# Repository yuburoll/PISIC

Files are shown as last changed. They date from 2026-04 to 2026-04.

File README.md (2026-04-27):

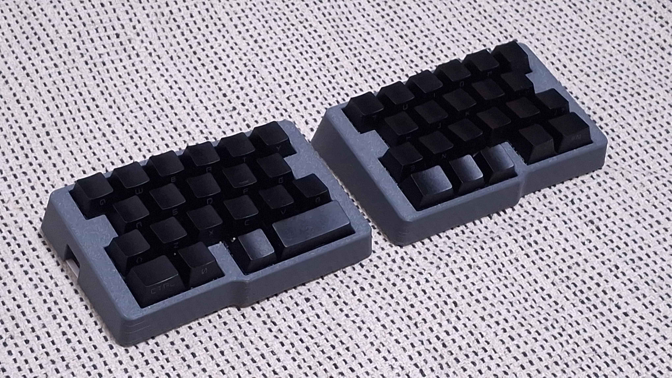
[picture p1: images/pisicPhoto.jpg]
pisicPhoto


# PISIC
42-44key row staggered split keyboard with GRIN inspired layout, under 102mm PCB

The name PISIC means grin in korean, also is korean pun of grin layout of [ansic](https://github.com/yuburoll/ANSIC).

## Preparation

- 2x pro micro form factor dev board

- 2x PISIC PCB Boards, provided from the repo

- 1x printed case sets, 2 parts total, provided from the repo

- 2x 1.5-1.6T keyboard plates, provided from the repo

- 2x 1.5-1.6T back plates, provided from the repo

- 44x diodes

- 46x Kailh hotswap sockets (or compatibles)

- 24x M2x6 screws, flathead

- 2x PJ320A 1/8(3.5mm) TRRS connector

- 2x 4x4x1.5mm surface mount tact switches (if needed)

- 8x SK6812 Mini or WS2812b Mini (3535) RGB LED (if wanted)

- 1x 1/8(3.5mm) TRRS cable

- 0-2x PCB Mounted 2u Keyboard Stabilizers, normally 1 

- 42-44x MX Keyswitches, normally 43

- 8x 10mm bumpon stickers

- A set of Keycaps

## Build Guides and Miscellaneous

[**PISIC Build Guide**](documents/buildGuide.md)

there's some notices before the build:

- **You may solder all hotswaps before soldering the dev board.**

- Assemble dev board with 2.5mm height pin headers on back side, assume that components side are faced up.

- Jump every jumpers on front side.

- Assemble Case-Plate-Switch first, not Plate-Switch-PCB.

## Default Keymap

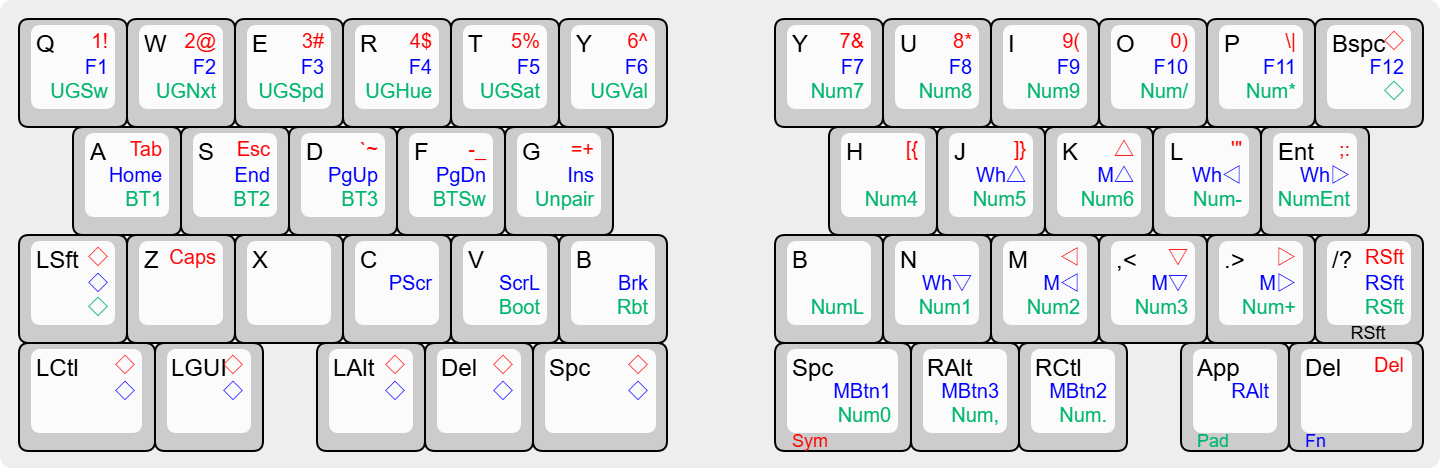
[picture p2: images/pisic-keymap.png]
pisicKeymap


There are three more layers - Sym, Fn, Pad - which can be noticed by the color legends. ◇ Means Transparent; which uses base keymap.

Holding the color legend key swaps the layer.

## Licenses

all codes follow MIT license.

all designs and the hardware board follow CC BY-SA 4.0 license.

If you want to make a commercial product, it would be appreciated if you sponsor some bucks for me.

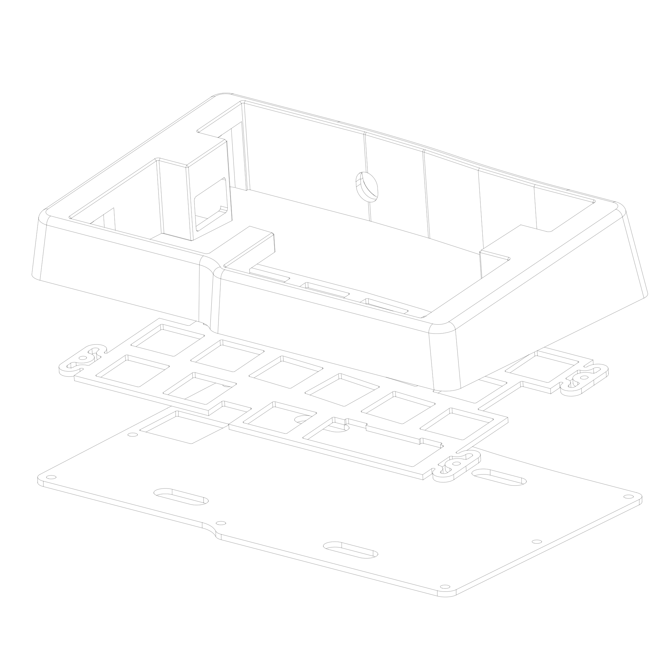
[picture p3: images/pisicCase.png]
pisicCase


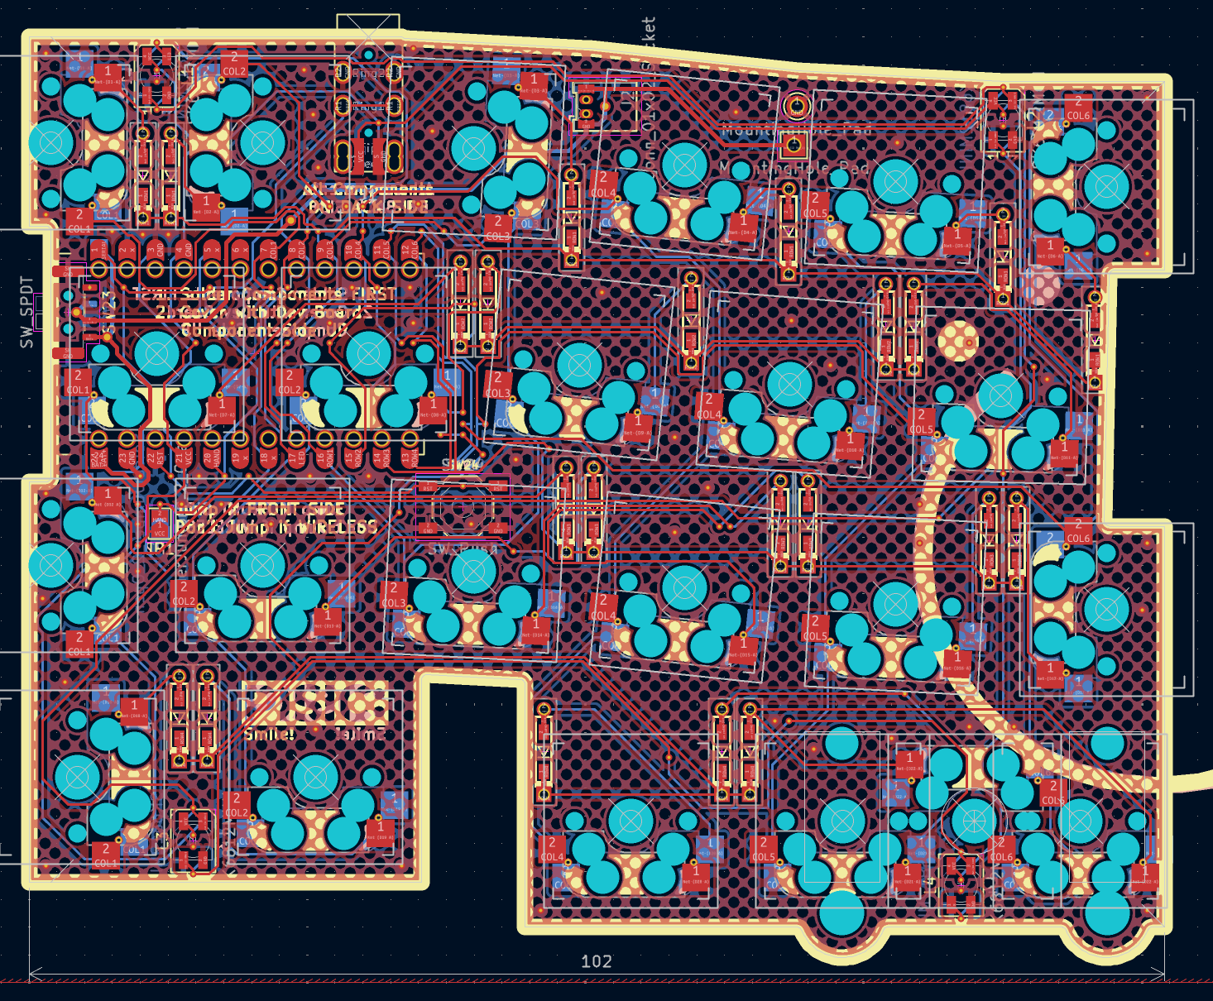
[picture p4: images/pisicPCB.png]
pisicPCB


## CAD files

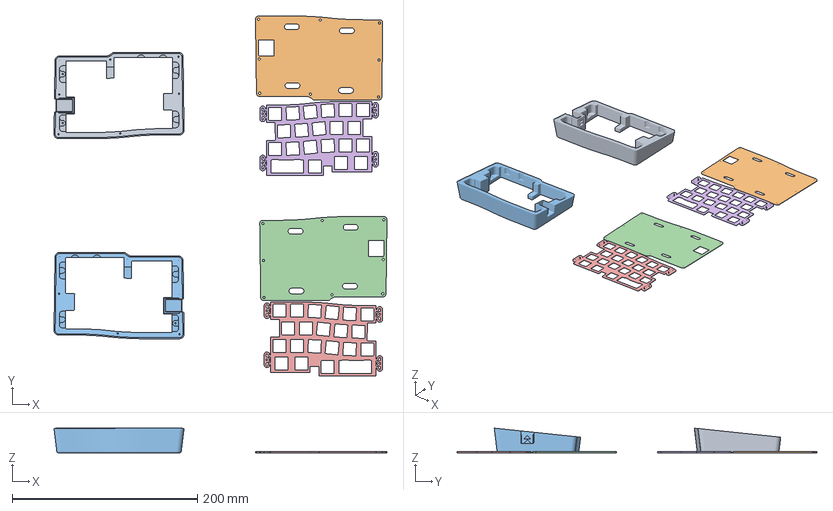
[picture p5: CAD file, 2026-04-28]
case/3mf/pisicWireless.3mf
359.5 x 388.6 x 26.7 mm
pisicCaseWirelessBridgedL.stl x 2
pisicBackplateBridgeL.stl x 2
pisicPlateL.stl x 2

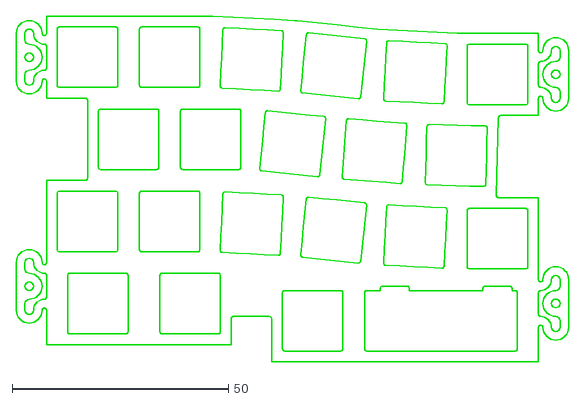
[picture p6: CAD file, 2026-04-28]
case/platesVector/pisicPlate.dxf
127.8 x 80.0

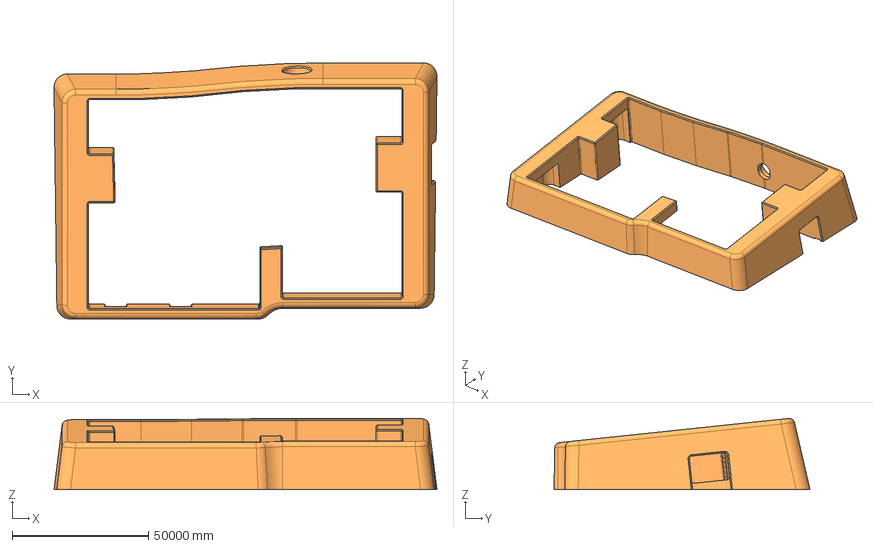
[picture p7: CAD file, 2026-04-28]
case/step/pisicCaseWiredR.stp
140382.8 x 93848.9 x 26067.8 mm

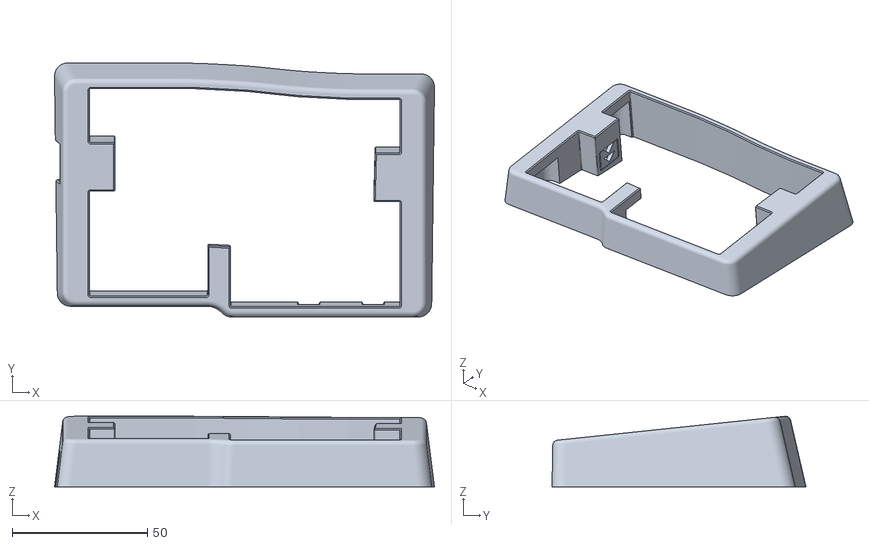
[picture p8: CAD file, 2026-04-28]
case/stl/FDMoptimized/pisicCaseWirelessBridgedL.stl
140.4 x 93.8 x 26.1

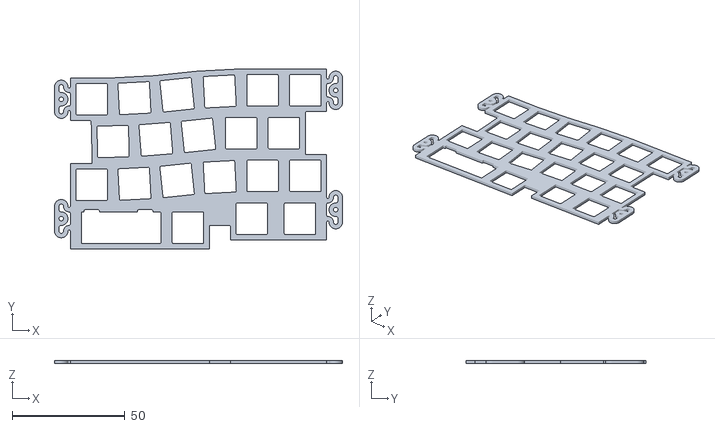
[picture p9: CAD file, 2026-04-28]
case/stl/pisicPlateR.stl
127.8 x 80.0 x 1.50

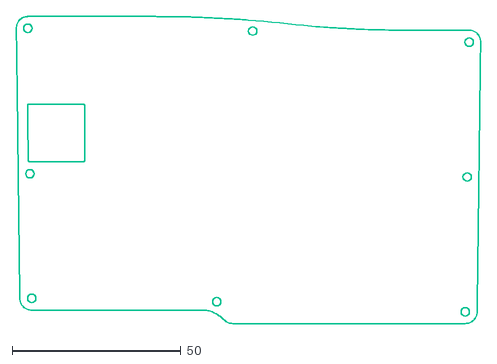
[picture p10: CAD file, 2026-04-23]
case/platesVector/pisicBackplate.dxf
137.4 x 90.9

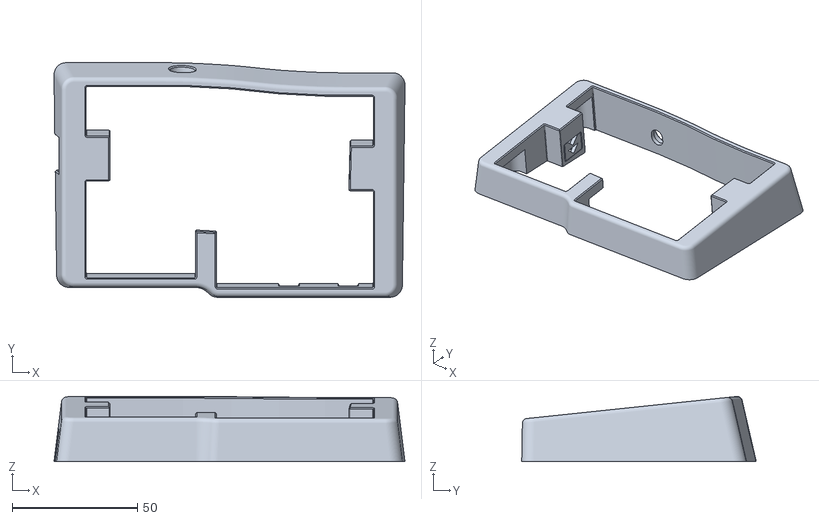
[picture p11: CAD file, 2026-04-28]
case/stl/FDMoptimized/pisicCaseWiredBridgedL.stl
140.4 x 93.8 x 26.1

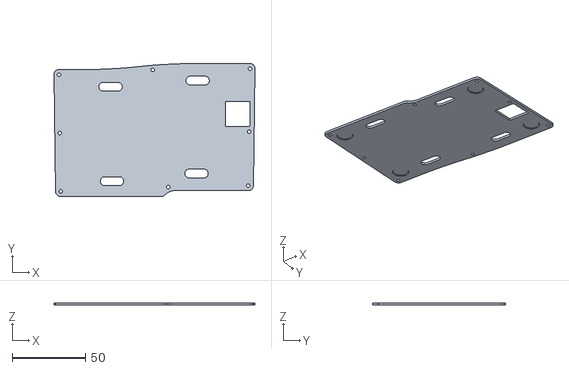
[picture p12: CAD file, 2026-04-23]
case/stl/pisicBackplateR.stl
137.4 x 90.8 x 1.50

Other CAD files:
case/3mf/pisicWired.3mf
case/step/pisicCaseWirelessR.stp
case/stl/pisicPlateL.stl
case/step/pisicCaseWirelessL.stp
case/stl/FDMoptimized/pisicCaseWiredBridgedR.stl
case/step/pisicCaseWiredL.stp
case/stl/FDMoptimized/pisicCaseWirelessBridgedR.stl
case/stl/pisicBackplateL.stl
case/stl/FDMoptimized/pisicBackplateBridgeL.stl
case/stl/FDMoptimized/pisicBackplateBridgeR.stl
case/raw/pisic.3dm
case/stl/pisicCaseWiredL.stl
case/stl/pisicCaseWiredR.stl
case/stl/pisicCaseWirelessL.stl
case/stl/pisicCaseWirelessR.stl

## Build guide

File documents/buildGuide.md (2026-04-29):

# Build Guide
this is build guide for PISIC.

the build guide contains photo of prototype version. newest version have following differences:

- the rims between first row and third row are 4mm wider, for easier assembly. these PCB have outline silkscreen.

- the corner screws of case aside fourth row are enforced, so they also have different plate design.

This documents are translated by generative AI, so there can be some misleading texts.

### Additional Resources
[**Soldering Tips**](solderingTip.md)

# PCB Preparation
Prepare two PCBs for the PISIC. Since these are reversible PCBs, be careful to place components on different sides for each board.

The side where components will be placed is treated as the back, and the side without components is treated as the front. **All components go on back side only, so please be careful when soldering.**

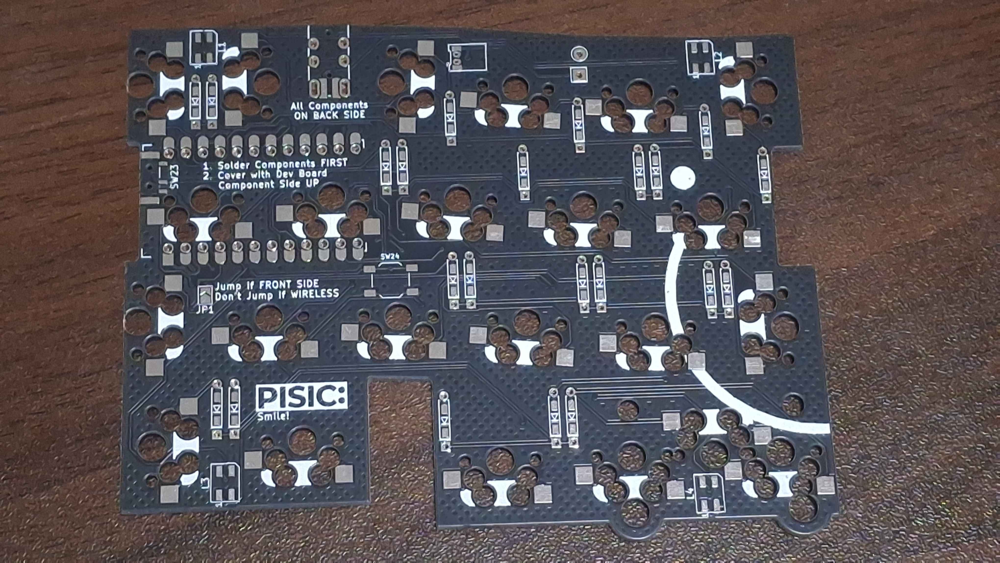
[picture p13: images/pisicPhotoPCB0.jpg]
pisicPhotoPCB0

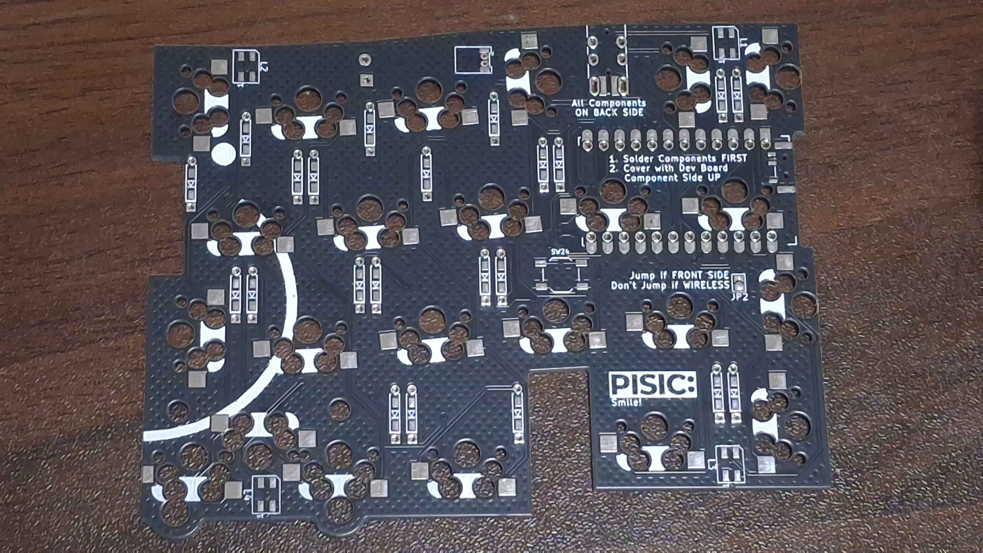
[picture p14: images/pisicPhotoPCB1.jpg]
pisicPhotoPCB1


# Soldering the Diodes
Solder the diodes. The photos show SMD diodes being used, but THT diodes can also be used.

When using SMD diodes, first apply a solder blob to one side of the pad with a soldering iron, as shown in the following photo.

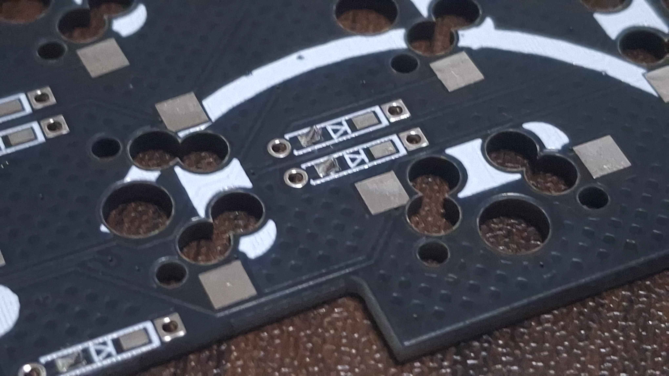
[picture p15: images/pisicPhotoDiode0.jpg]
pisicPhotoDiode0


Reheat the solder blob with the iron to melt it, align the diode in the correct orientation and place it in position, then remove the iron.

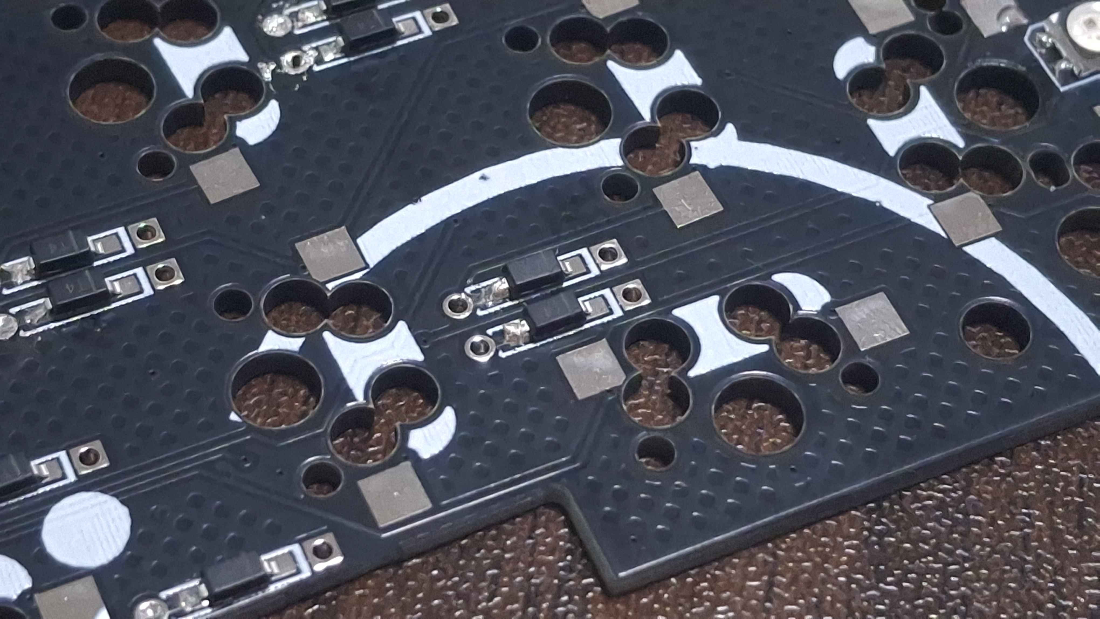
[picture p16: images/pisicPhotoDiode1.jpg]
pisicPhotoDiode1


Once it is seated properly, solder the opposite leg.

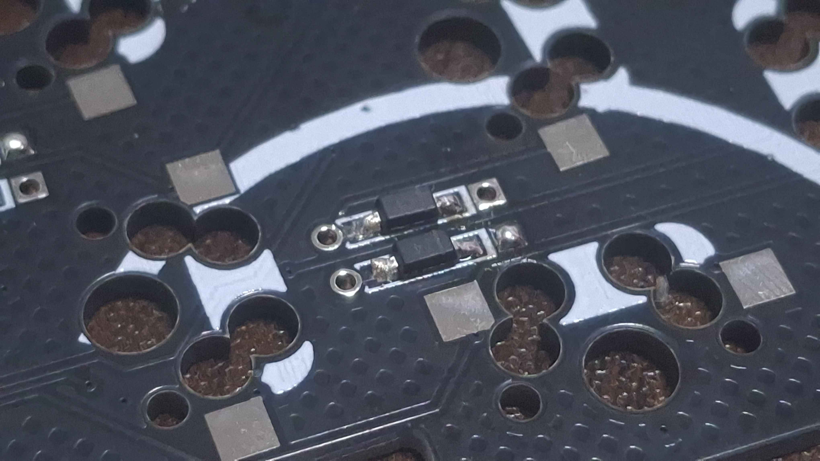
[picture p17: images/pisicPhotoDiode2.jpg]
pisicPhotoDiode2


# (Optional) Soldering the LEDs
Solder the underglow LEDs. The process is largely the same as soldering SMD diodes, but extra care is needed when applying heat.

First, apply a solder blob to one side of the pad with a soldering iron, as shown in the following photo.

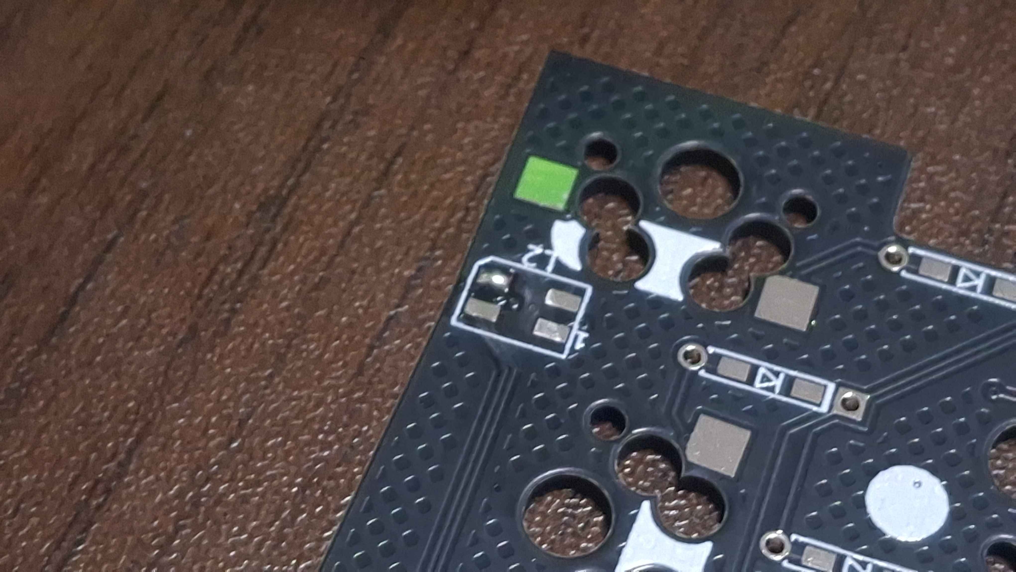
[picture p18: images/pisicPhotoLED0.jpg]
pisicPhotoLED0


Reheat the solder blob with the iron to melt it, align the LED in the correct orientation and place it in position, then remove the iron.

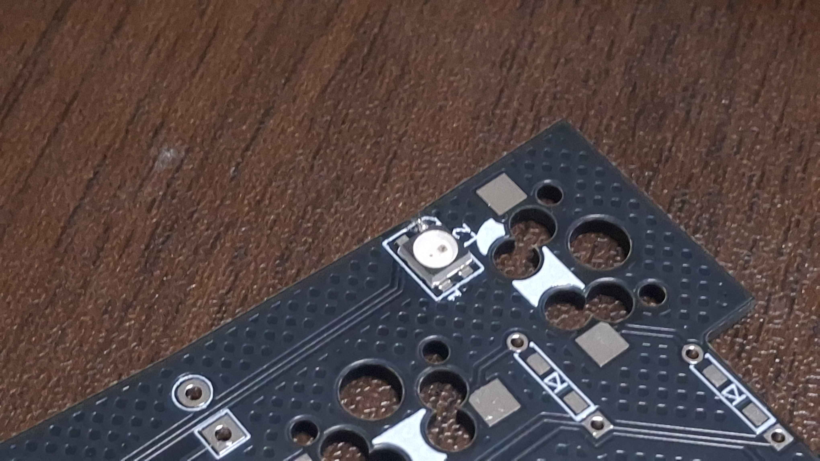
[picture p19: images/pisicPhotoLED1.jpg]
pisicPhotoLED1


Once it is seated properly, carefully solder the remaining three pads. Note that solder may not flow into them easily, so take care.

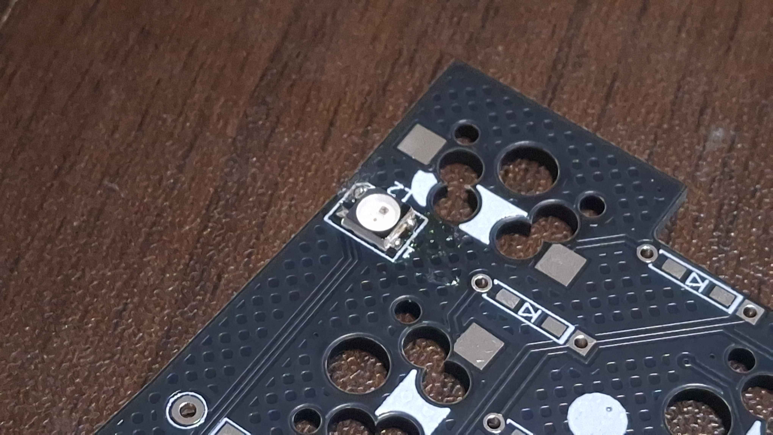
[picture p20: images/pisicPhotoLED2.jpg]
pisicPhotoLED2


# Soldering the Hot-swap Sockets
Solder the hot-swap sockets. The process is largely the same as soldering the diodes and LEDs.

As before, apply a solder blob to one side of the pad, reheat the blob to melt it, place the component and hold it in position, remove the iron, then solder the opposite leg.

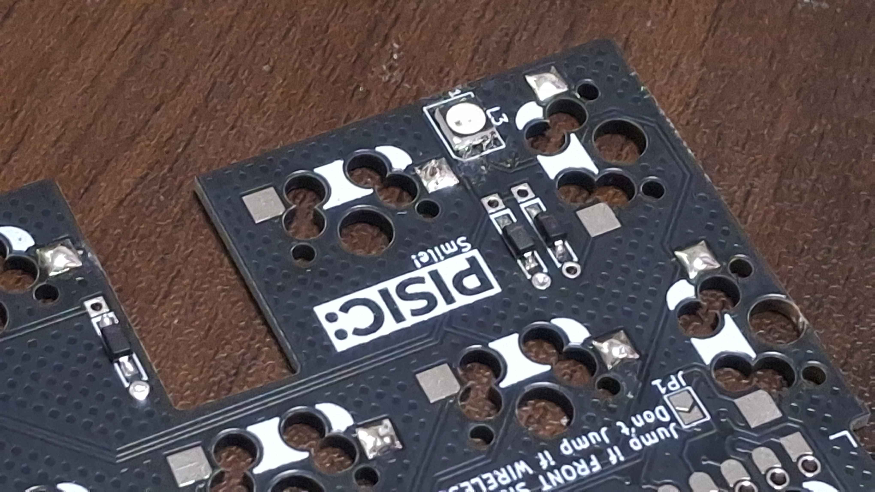
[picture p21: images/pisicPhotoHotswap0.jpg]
pisicPhotoHotswap0

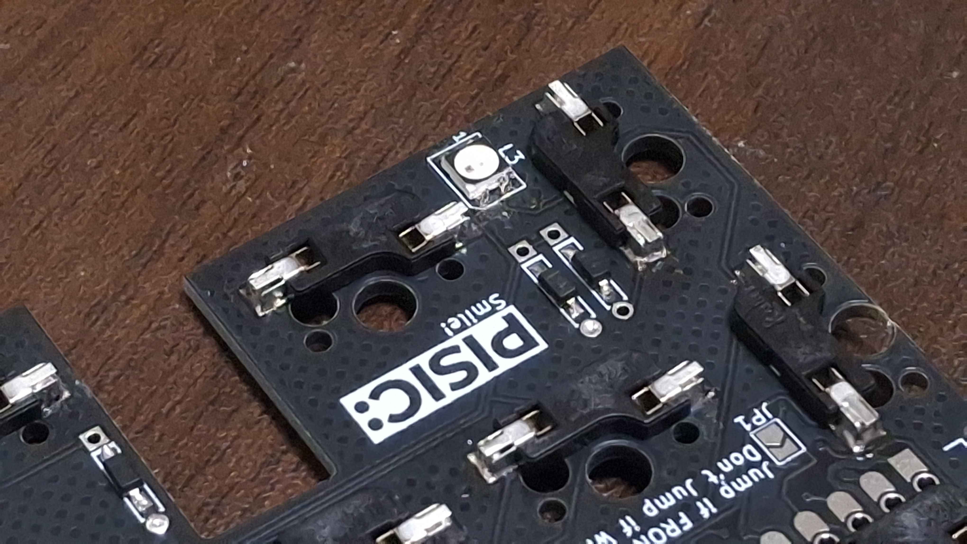
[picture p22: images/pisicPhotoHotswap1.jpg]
pisicPhotoHotswap1


# Soldering the TRRS Jack
Refer to the following photos to identify where the TRRS jack will be placed.

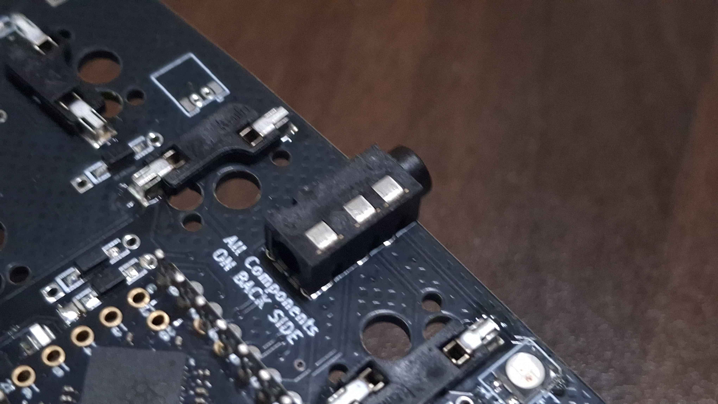
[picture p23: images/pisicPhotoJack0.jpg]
pisicPhotoJack0

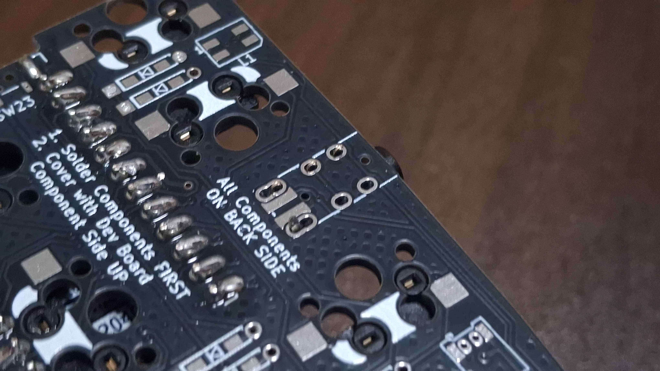
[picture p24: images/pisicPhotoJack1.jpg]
pisicPhotoJack1


Solder the TRRS jack. When soldering the Tip and Sleeve pins, also bridge them to the adjacent pads as shown in the photo.

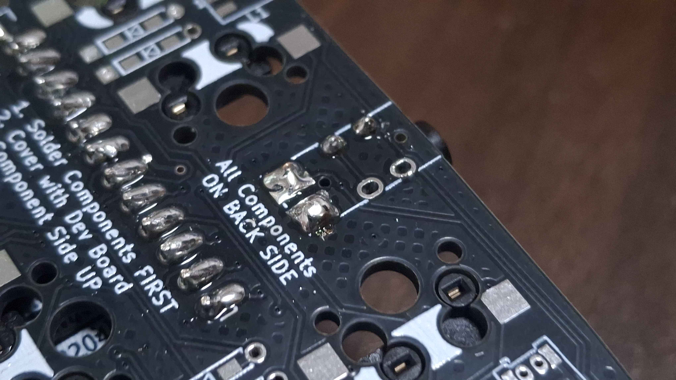
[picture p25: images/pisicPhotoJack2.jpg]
pisicPhotoJack2


# Soldering the Dev Board
First, check the header pins on the provided Pro Micro dev board. The outermost row of header pins past 5V is not needed, so trim them off.

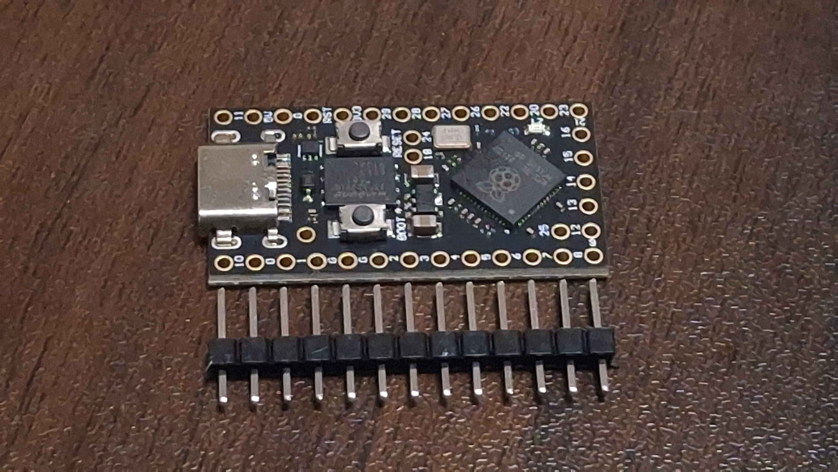
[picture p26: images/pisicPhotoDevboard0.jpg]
pisicPhotoDevboard0

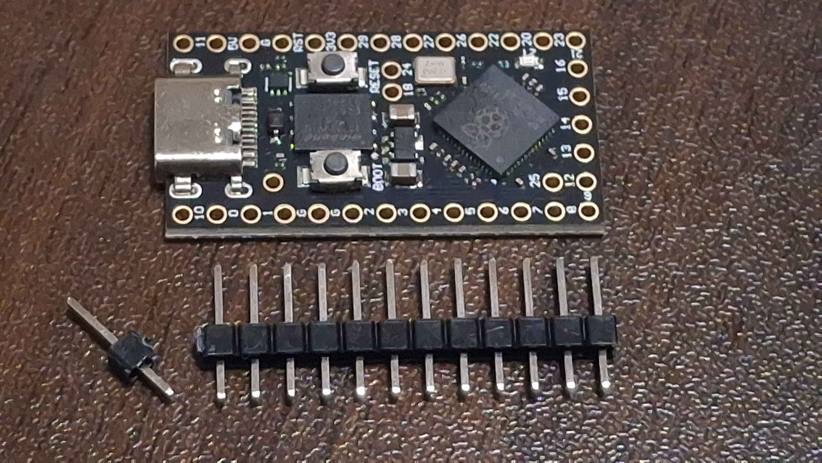
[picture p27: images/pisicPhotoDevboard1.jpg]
pisicPhotoDevboard1


Insert the header pins starting from 5V, align them, and solder the dev board. When soldering, make sure the components face upward as shown in the photo.

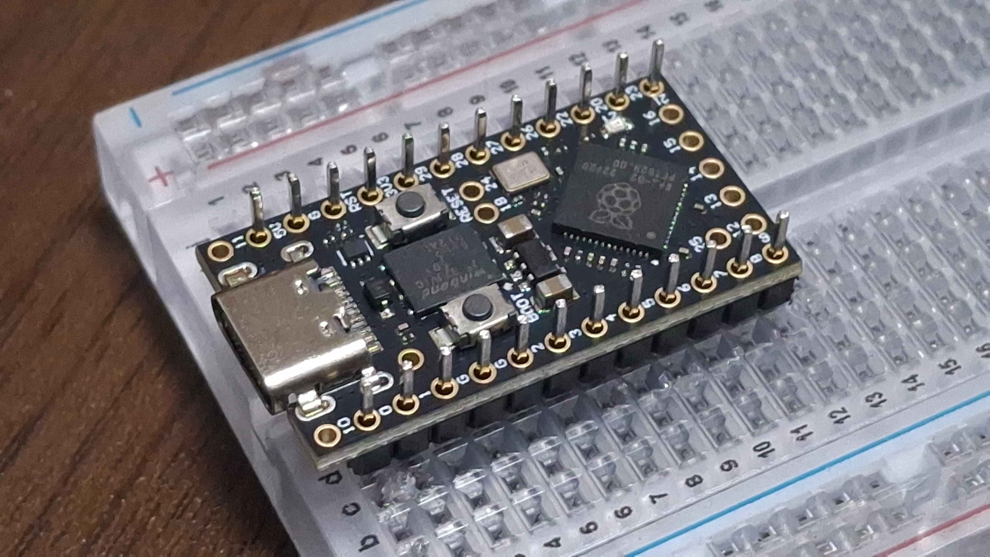
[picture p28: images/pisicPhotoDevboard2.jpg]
pisicPhotoDevboard2

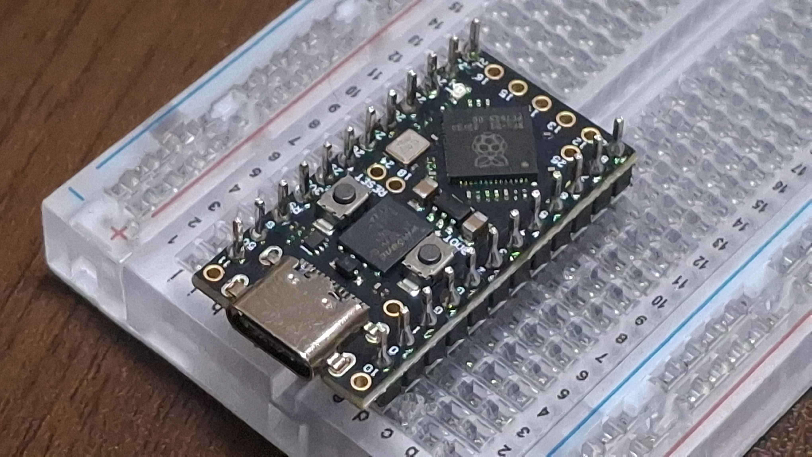
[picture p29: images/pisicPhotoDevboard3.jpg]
pisicPhotoDevboard3


Place the dev board with the soldered header pins on top of the already-soldered hot-swap sockets. Press down firmly to ensure a tight fit.

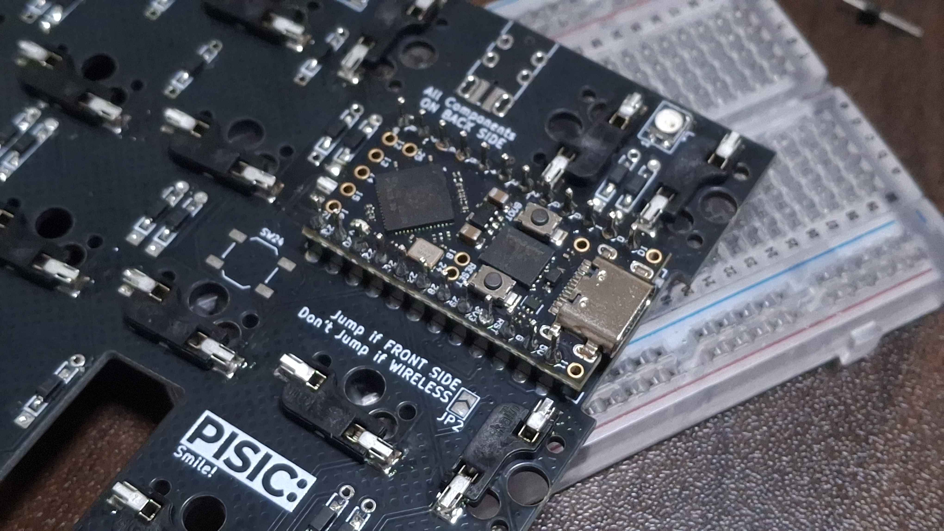
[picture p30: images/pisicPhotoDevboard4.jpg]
pisicPhotoDevboard4

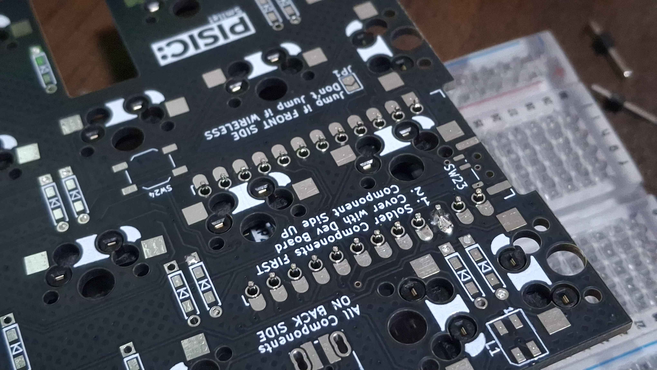
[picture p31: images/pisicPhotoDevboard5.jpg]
pisicPhotoDevboard5


Just like when soldering the TRRS jack pins, bridge the header pins to the adjacent pads as if soldering jumpers. Since a large amount of solder is used, there is a risk of bridging with flux, so be sure to clean the area with alcohol after soldering.

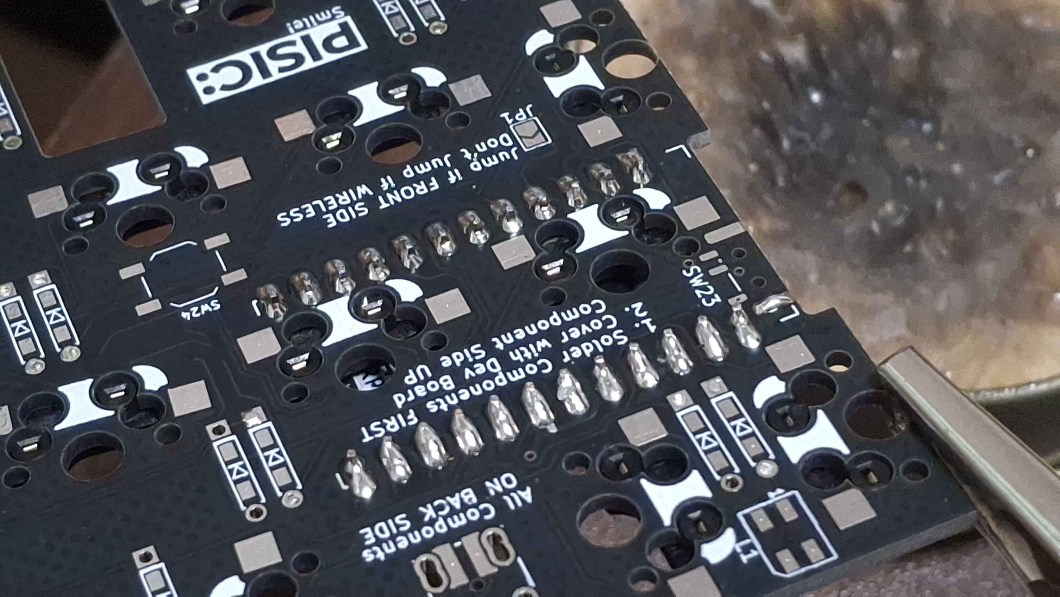
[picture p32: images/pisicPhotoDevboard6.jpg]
pisicPhotoDevboard6


# Soldering the Jumpers
On the front side seen when soldering the dev board, bridge the jumpers located just below. Apply enough solder so that a blob forms on top.

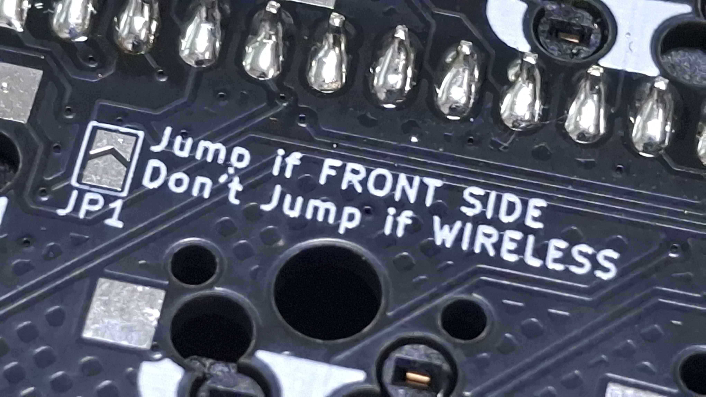
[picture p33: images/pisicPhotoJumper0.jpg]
pisicPhotoJumper0

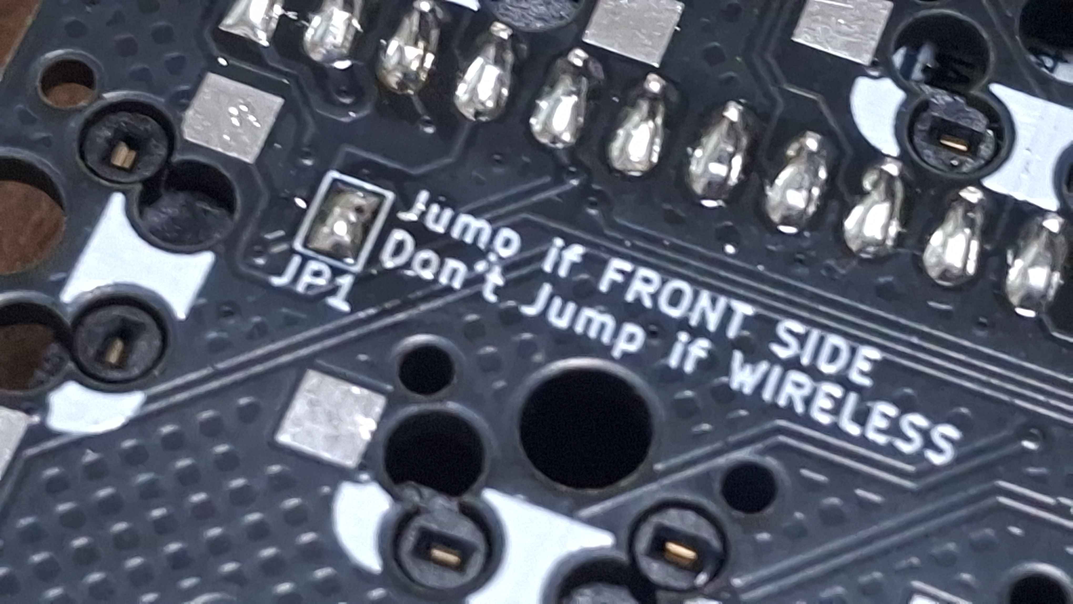
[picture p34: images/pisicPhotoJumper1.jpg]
pisicPhotoJumper1


# Check before Assembly
a finished right side of PCB looks like following images. mirror it on the left side.

the photo didn't jumped the front jumper, but you may jump there if you building wired version.

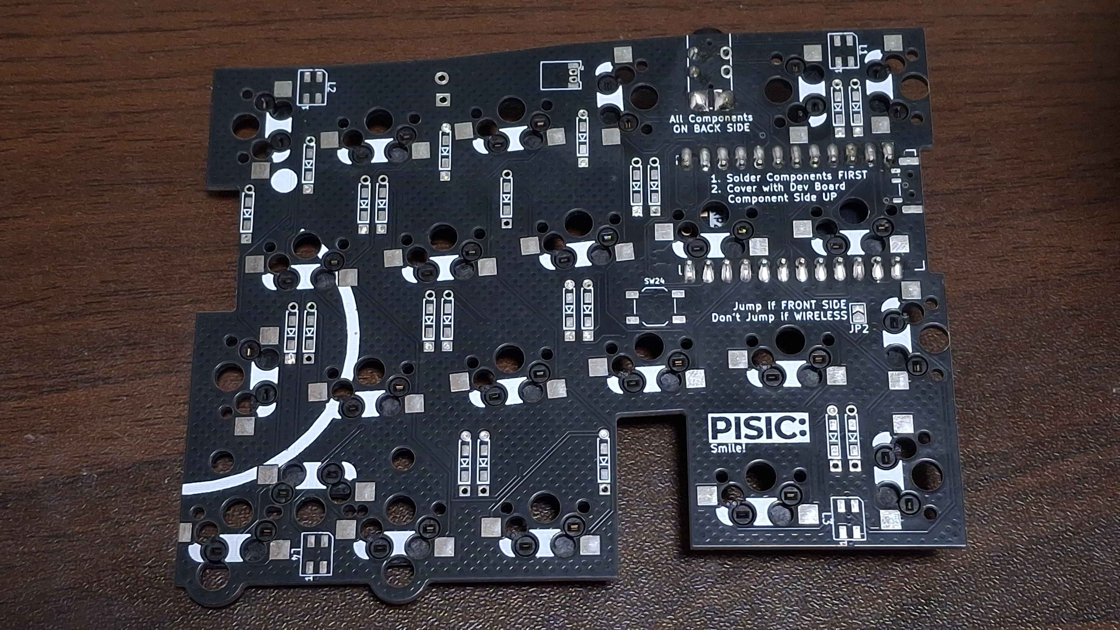
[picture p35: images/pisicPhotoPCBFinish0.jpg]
pisicPhotoPCBFinish0

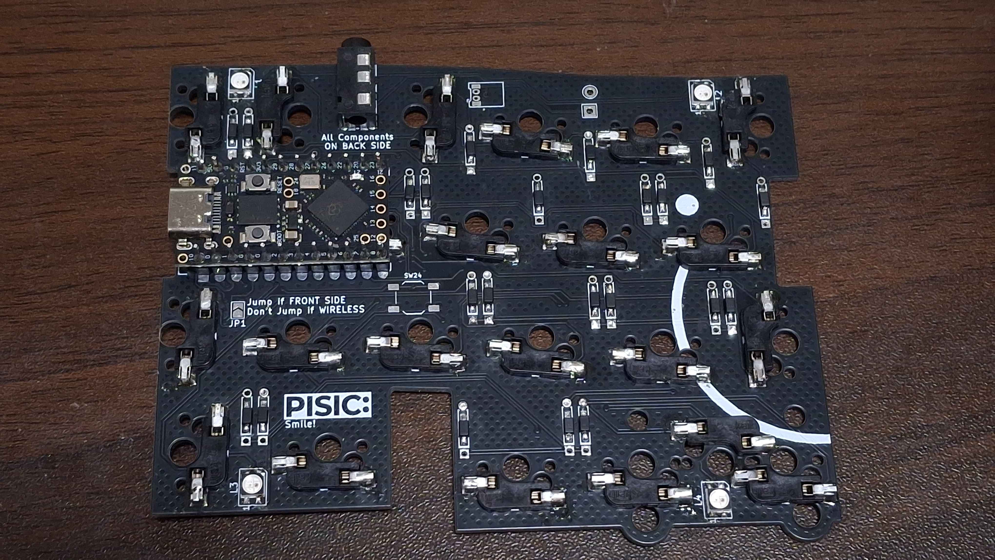
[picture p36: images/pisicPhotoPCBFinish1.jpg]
pisicPhotoPCBFinish1


# Assembly
First, assemble the case, plate, and switches together. (Note: If you assemble the plate, switches, and PCB first, the assembly will not fit into the case.)
The plate and case are fastened together with screws at four points.

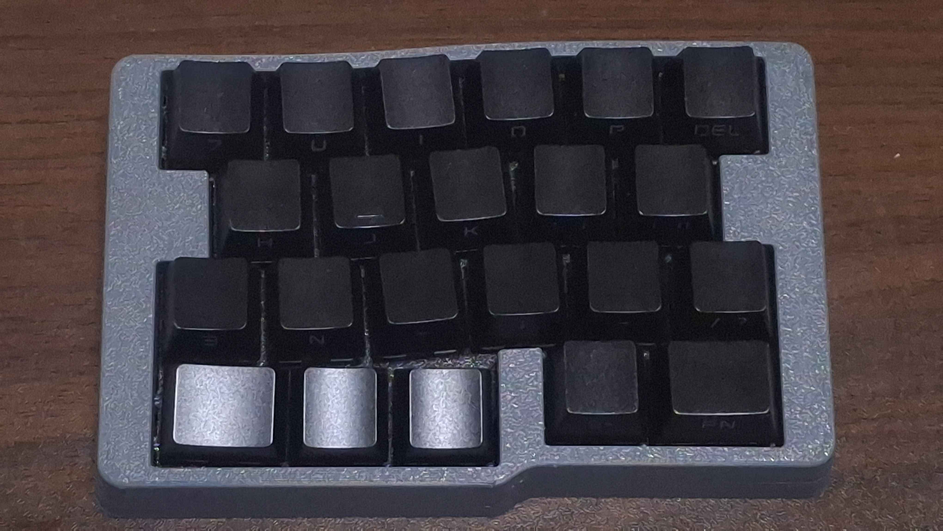
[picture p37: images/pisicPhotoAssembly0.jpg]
pisicPhotoAssembly0

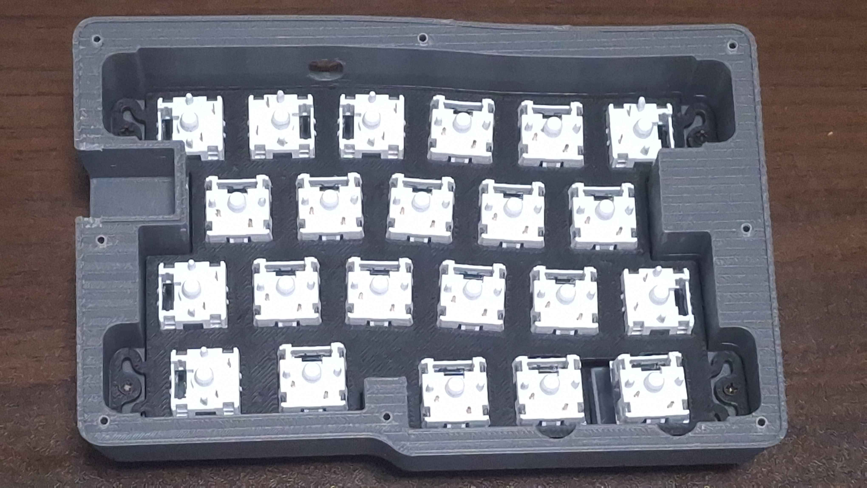
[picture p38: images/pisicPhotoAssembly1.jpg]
pisicPhotoAssembly1


Insert the protruding part of the TRRS jack into the hole in the case, then lower the PCB onto the switches to mate them together.

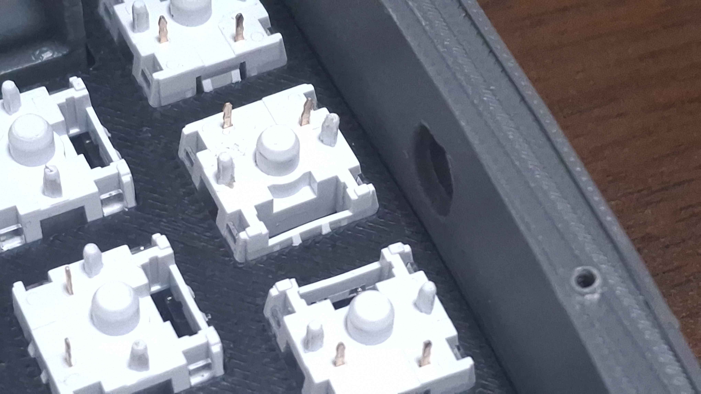
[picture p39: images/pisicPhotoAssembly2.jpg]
pisicPhotoAssembly2

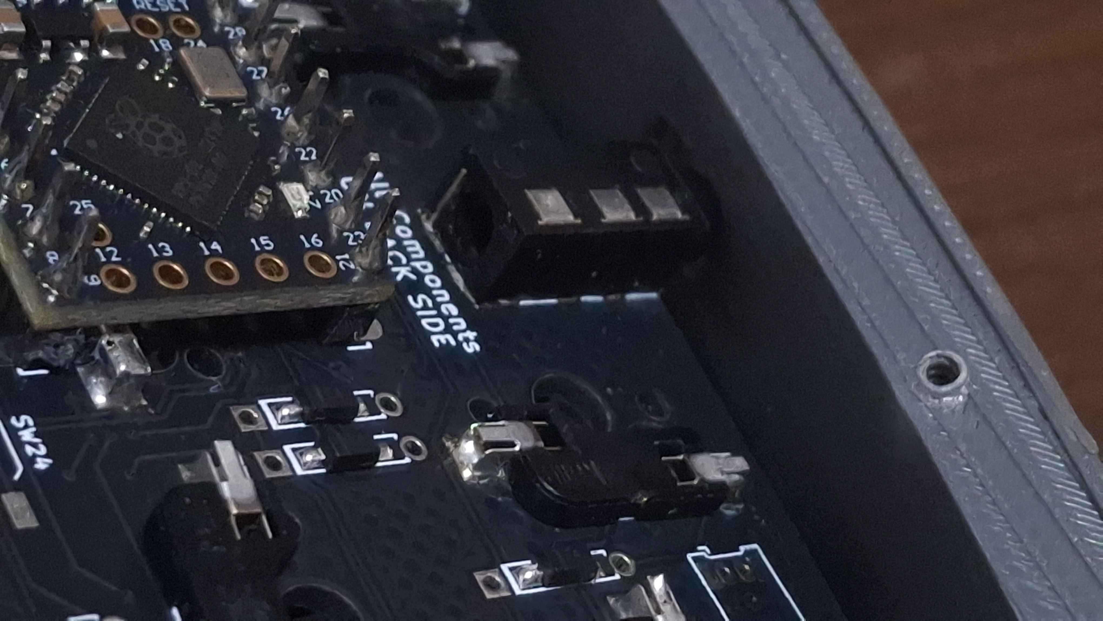
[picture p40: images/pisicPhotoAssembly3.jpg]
pisicPhotoAssembly3


Place the backplate over the case and fasten it with screws at eight points per side to complete the build.

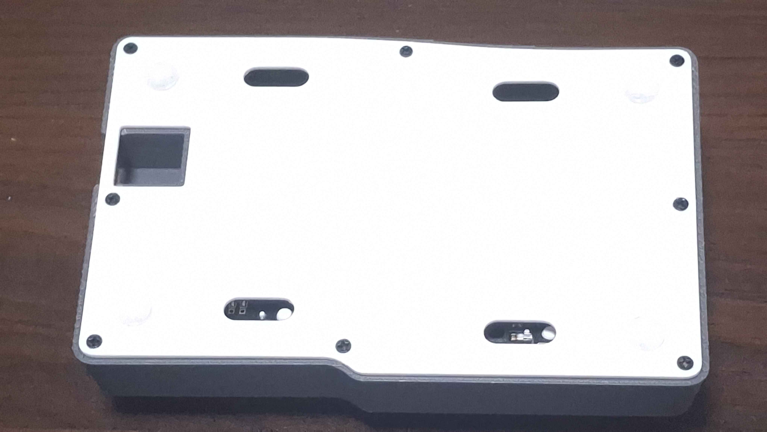
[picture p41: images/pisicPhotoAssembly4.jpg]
pisicPhotoAssembly4


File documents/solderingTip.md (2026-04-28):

# Soldering Tips

A collection of soldering advice and tips.

This documents are translated by generative AI, so there can be some misleading texts.

## Supplies

- Soldering iron & stand: A chisel tip is the most convenient to work with. I recommend getting one that can maintain a temperature of at least 400–500°C.

- Solder: Choose between leaded and lead-free solder. Leaded solder is less stressful to work with, but it is not good for your health.

- Solder paste (flux): **The god of soldering.** If your solder joints are not turning out well, frequently wipe and coat the iron tip with paste flux.

- Damp sponge/paper towel, or a tip cleaner (brass wool): Used to wipe residual solder off the iron tip.

- Solder wick or solder sucker: Used to fix bad solder joints. For beginners, solder wick is recommended.

- Flush cutters: Used to clip the legs of THT diodes after soldering.

## Ventilate Your Workspace

The metal fumes from melting solder are a concern, but they are actually quite minimal. The bigger issue is the smoke from the rosin flux inside the solder burning and melting — it is quite harmful and produces a lot of smoke. It is very bad for your health, so ventilate the area, or if ventilation is not possible, make sure to use an air purifier. Always wear a mask.

## Double-Check Before Soldering Components

It is easier to prevent a bad solder joint than to fix one. To correct a solder joint, apply flux to solder wick and press it against the joint with the iron, or apply a small amount of flux to the iron tip, melt the solder, and simultaneously press a solder sucker against it to absorb the solder.

## Apply Flux If Solder Is Not Sticking

Melt flux onto the iron tip to coat it, or use a flux pen to apply it directly to the PCB pads.

## Touch the Iron First When Starting, Remove It Last When Finishing

Place the iron on the pad first to preheat the PCB and component, then melt the solder onto the joint. When finishing, remove the solder first, then remove the iron last.

## Use Masking Tape to Temporarily Hold Components

For components like sockets, securing them with masking tape before soldering is helpful. This is especially important when you need to flip the board over, as components can be difficult to hold in place.

## Clean the Flux After Soldering

Scrub the remaining flux and any areas prone to short circuits thoroughly using a toothbrush dipped in isopropyl alcohol. You can also spray alcohol on the board, scrub with a toothbrush, and let it dry. Keyboard key inputs may work fine with residual flux, but encoders and analog inputs are more susceptible to issues caused by flux bridging.

## If Something Goes Wrong, Reflow and Clean

Problems can arise from cold joints, insufficient solder, excess solder bridging neighboring pads, or electrical interference from flux residue. In most cases, reflowing the solder joint and cleaning the flux will resolve the issue.

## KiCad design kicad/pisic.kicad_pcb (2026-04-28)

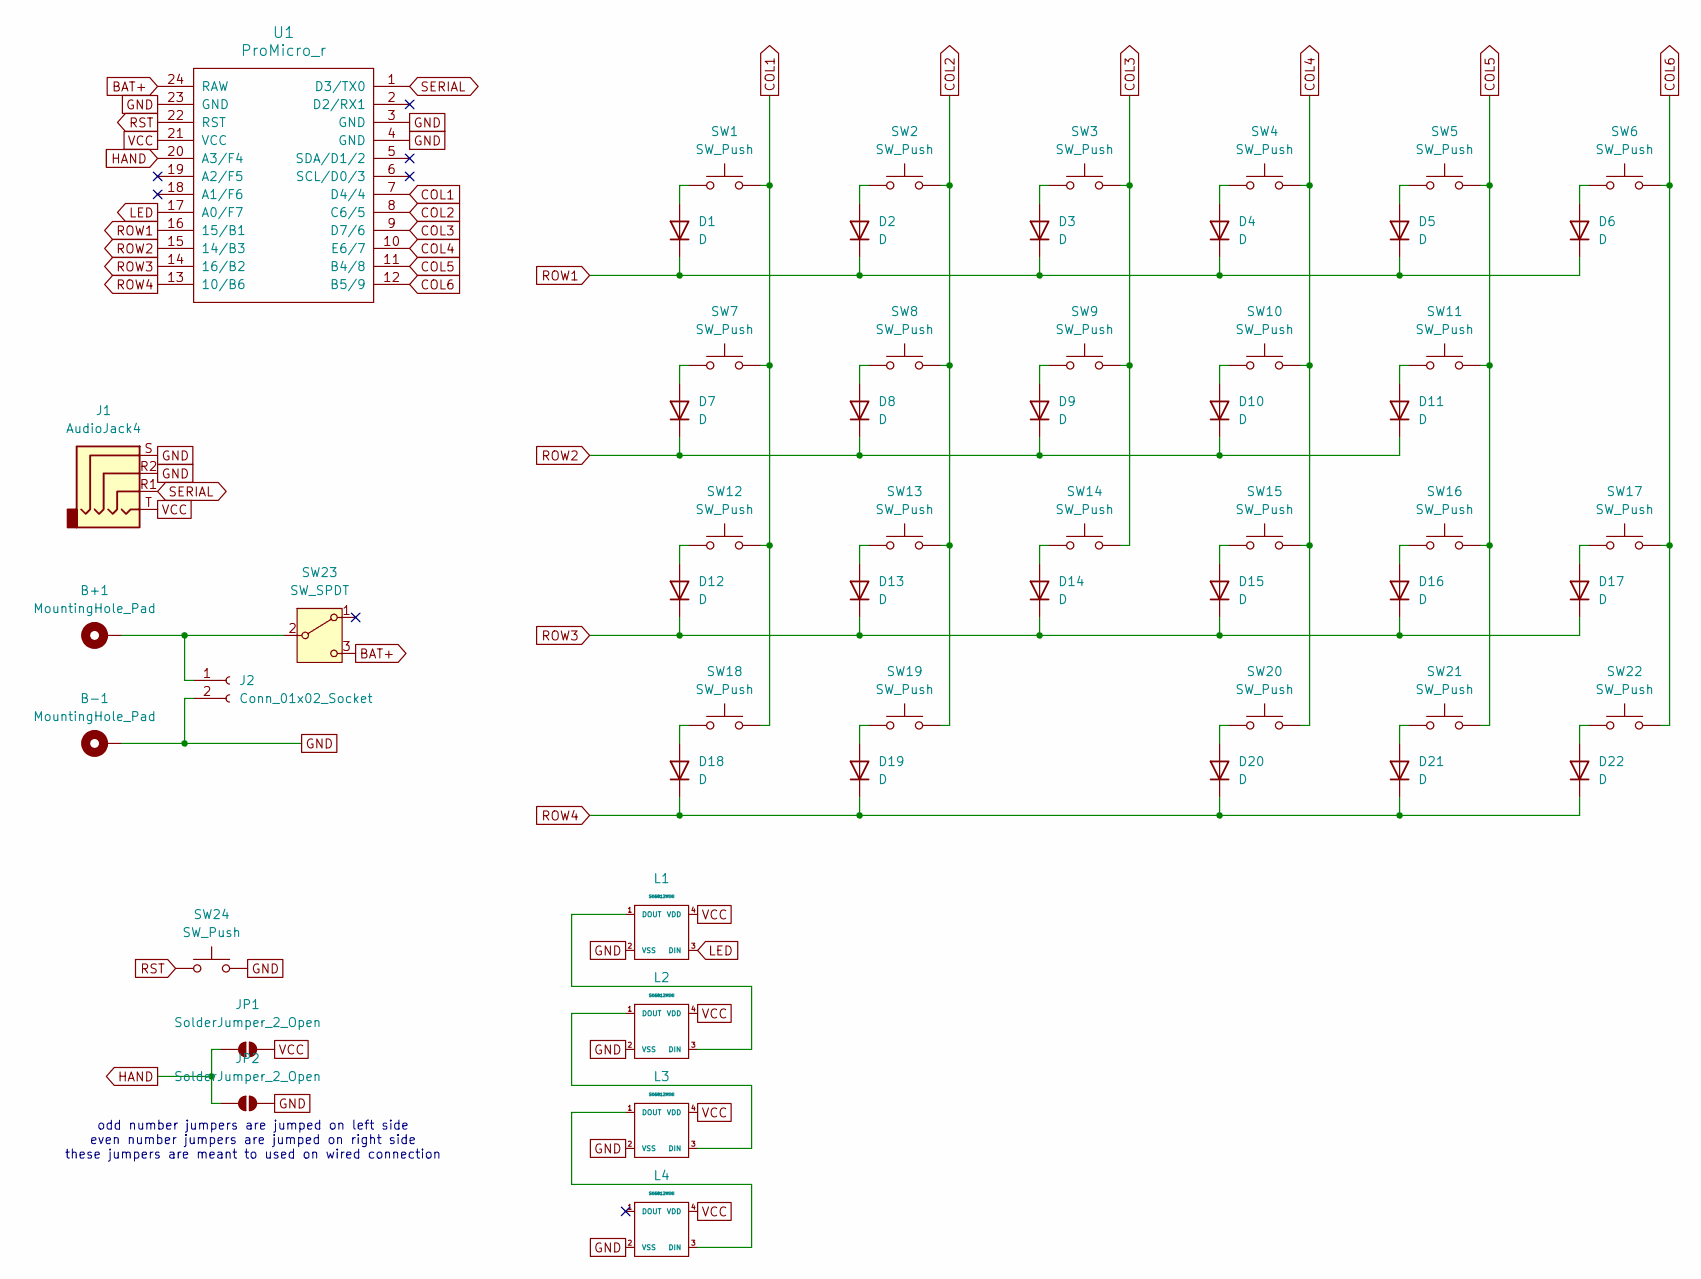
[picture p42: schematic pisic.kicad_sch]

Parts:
B+1: MountingHole_Pad
B-1: MountingHole_Pad
D1, D2, D3, D4, D5, D6, D7, D8, D9, D10, D11, D12, D13, D14, D15, D16, D17, D18, D19, D20, D21, D22: D
J1: AudioJack4
J2: Conn_01x02_Socket
JP1, JP2: SolderJumper_2_Open
L1, L2, L3, L4: SK6812MINI
SW1, SW2, SW3, SW4, SW5, SW6, SW7, SW8, SW9, SW10, SW11, SW12, SW13, SW14, SW15, SW16, SW17, SW18, SW19, SW20, SW21, SW22, SW24: SW_Push
SW23: SW_SPDT
U1: ProMicro_r

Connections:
BAT+: SW23.3 (C), U1.24 (RAW)
COL1: SW1.2, SW7.2, SW12.2, SW18.2, U1.7 (D4/4)
COL2: SW2.2, SW8.2, SW13.2, SW19.2, U1.8 (C6/5)
COL3: SW3.2, SW9.2, SW14.2, U1.9 (D7/6)
COL4: SW4.2, SW10.2, SW15.2, SW20.2, U1.10 (E6/7)
COL5: SW5.2, SW11.2, SW16.2, SW21.2, U1.11 (B4/8)
COL6: SW6.2, SW17.2, SW22.2, U1.12 (B5/9); also elsewhere on the board
GND: B-1.1, J1.R2, J1.S, J2.2, JP2.1 (A), L1.2 (VSS), L2.2 (VSS), L3.2 (VSS), L4.2 (VSS), SW23.SH, SW24.2, U1.3 (GND), U1.4 (GND), U1.23 (GND); also elsewhere on the board
HAND: JP1.2 (B), JP2.2 (B), U1.20 (A3/F4)
LED: L1.3 (DIN), U1.17 (A0/F7); also elsewhere on the board
unnamed: D1.2 (A), SW1.1
unnamed: D2.2 (A), SW2.1
unnamed: D3.2 (A), SW3.1
unnamed: D4.2 (A), SW4.1
unnamed: D5.2 (A), SW5.1
unnamed: D6.2 (A), SW6.1
unnamed: D7.2 (A), SW7.1
unnamed: D8.2 (A), SW8.1
unnamed: D9.2 (A), SW9.1
unnamed: D10.2 (A), SW10.1
unnamed: D11.2 (A), SW11.1
unnamed: D12.2 (A), SW12.1
unnamed: D13.2 (A), SW13.1
unnamed: D14.2 (A), SW14.1
unnamed: D15.2 (A), SW15.1
unnamed: D16.2 (A), SW16.1
unnamed: D17.2 (A), SW17.1
unnamed: D18.2 (A), SW18.1
unnamed: D19.2 (A), SW19.1
unnamed: D20.2 (A), SW20.1
unnamed: D21.2 (A), SW21.1
unnamed 31: D22.2 (A), SW22.1; also elsewhere on the board
unnamed: B+1.1, J2.1, SW23.2 (B)
unnamed 33: L1.1 (DOUT), L2.3 (DIN); also elsewhere on the board
unnamed 34: L2.1 (DOUT), L3.3 (DIN); also elsewhere on the board
unnamed 35: L3.1 (DOUT), L4.3 (DIN); also elsewhere on the board
ROW1: D1.1 (K), D2.1 (K), D3.1 (K), D4.1 (K), D5.1 (K), D6.1 (K), U1.16 (15/B1)
ROW2: D7.1 (K), D8.1 (K), D9.1 (K), D10.1 (K), D11.1 (K), U1.15 (14/B3)
ROW3: D12.1 (K), D13.1 (K), D14.1 (K), D15.1 (K), D16.1 (K), D17.1 (K), U1.14 (16/B2)
ROW4: D18.1 (K), D19.1 (K), D20.1 (K), D21.1 (K), D22.1 (K), U1.13 (10/B6)
RST: SW24.1, U1.22 (RST); also elsewhere on the board
SERIAL: J1.R1, U1.1 (D3/TX0)
VCC: J1.T, JP1.1 (A), L1.4 (VDD), L2.4 (VDD), L3.4 (VDD), L4.4 (VDD), U1.21 (VCC); also elsewhere on the board

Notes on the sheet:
odd number jumpers are jumped on left side even number jumpers are jumped on right side these jumpers are meant to used on wired connection

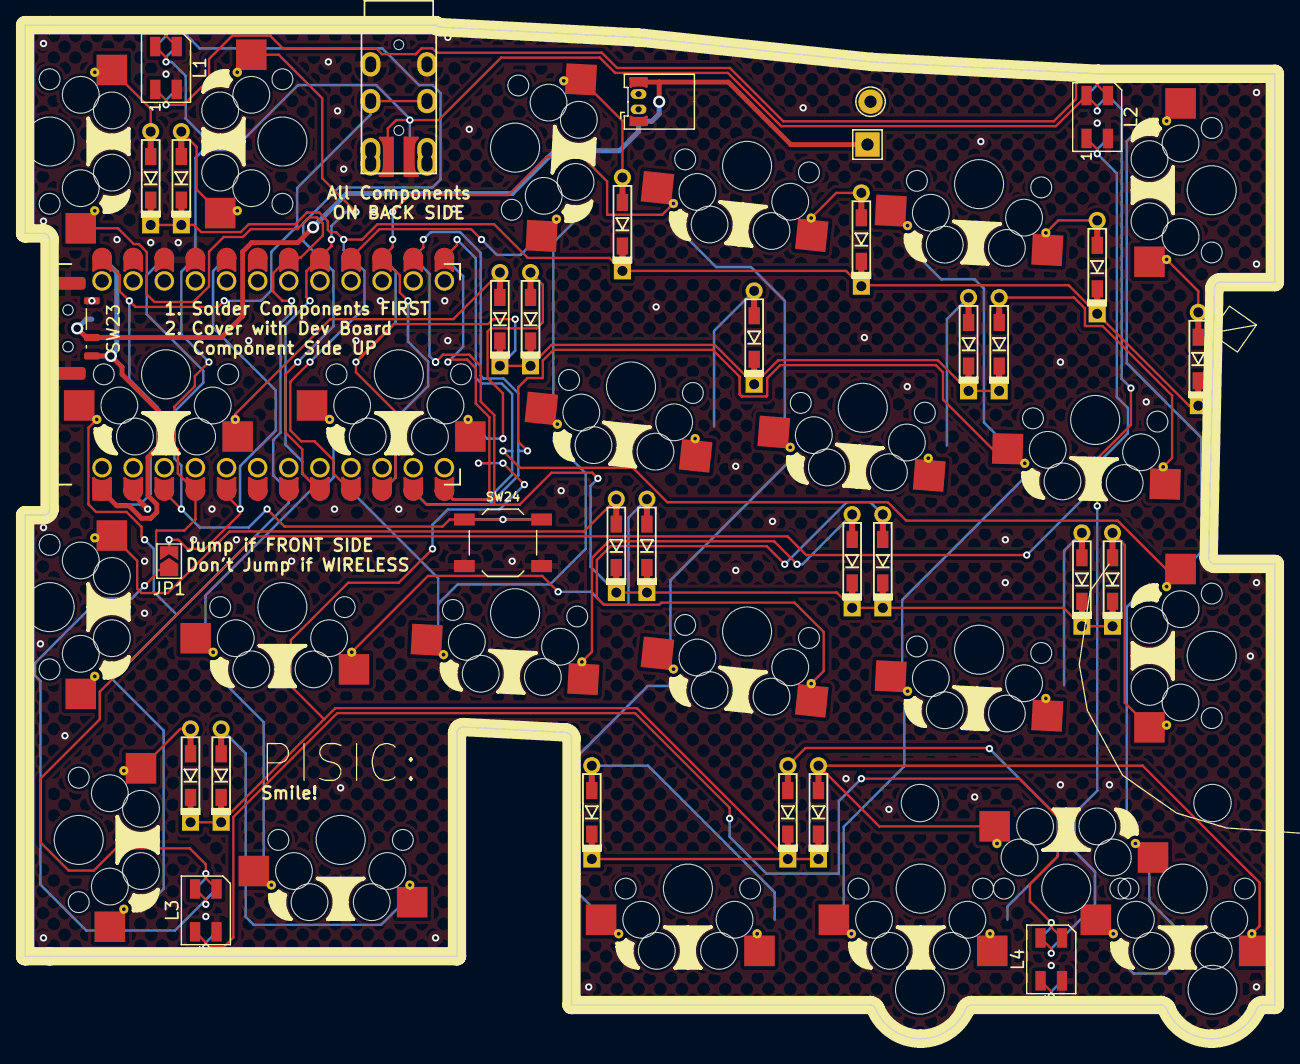
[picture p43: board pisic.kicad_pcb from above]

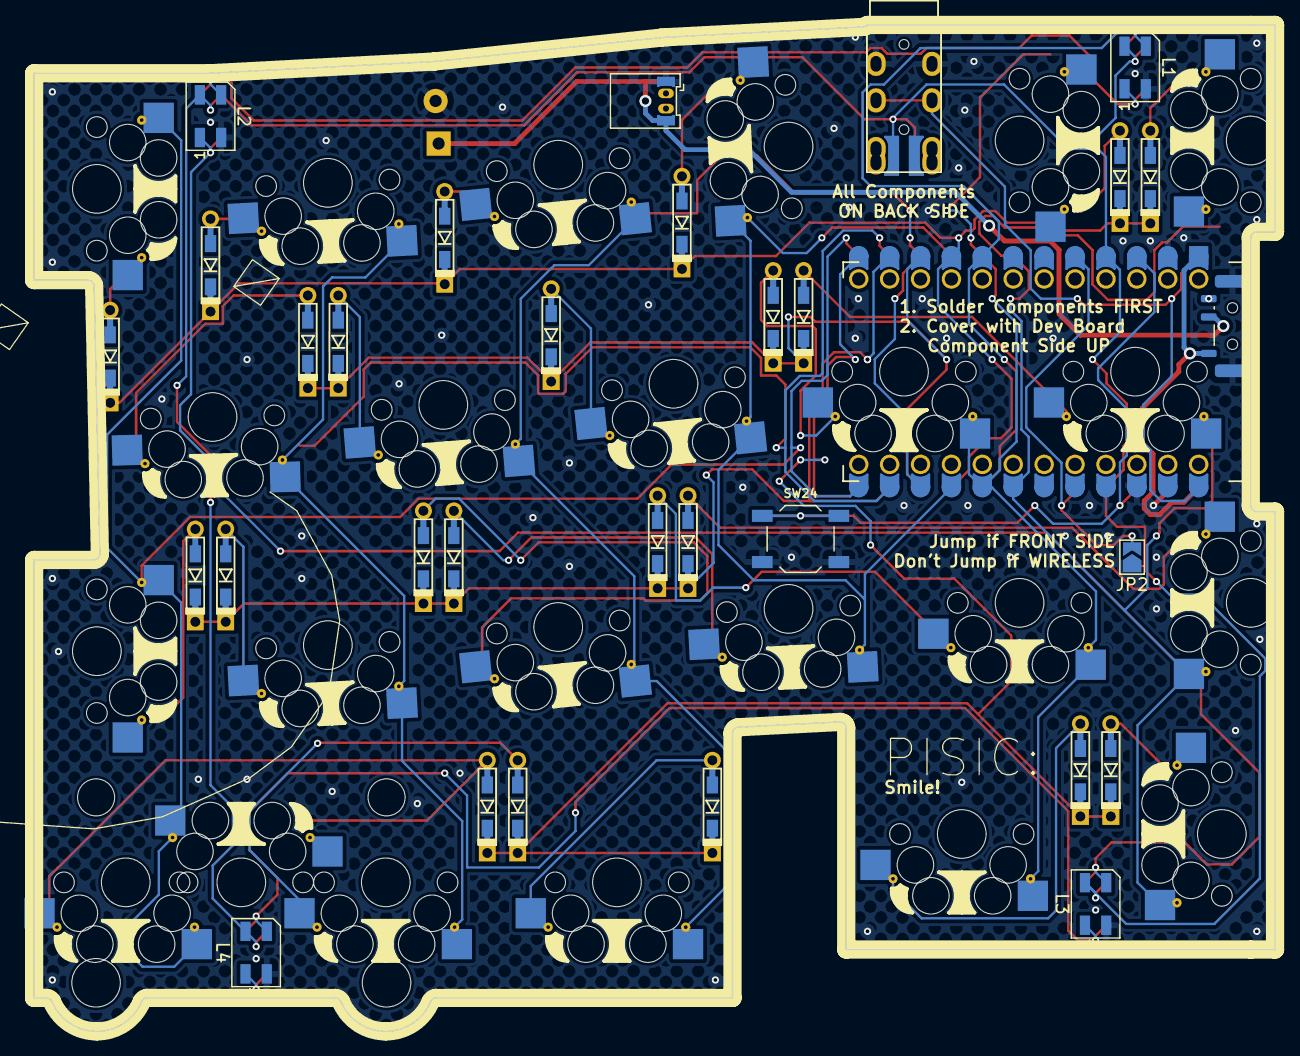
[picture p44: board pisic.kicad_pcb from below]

Board: 2 copper layers, 102.0 x 82.7 mm, 63 parts (6 on the bottom side), 43 nets.

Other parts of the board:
L1#2, L2#2, L3#2, L4#2: SK6812MINI; LED_SK6812MINI_PLCC4_3.5x3.5mm_P1.75mm
SW22#2: SW_Push; MX_Hotswap_FootprintPropertyFix_Guided
SW24#2: SW_Push; SW_SPST_TL3342

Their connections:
COL6: SW22#2.2; also elsewhere on the board
GND: L1#2.2 (VSS), L2#2.2 (VSS), L3#2.2 (VSS), L4#2.2 (VSS), SW24#2.2; also elsewhere on the board
LED: L1#2.3 (DIN); also elsewhere on the board
unnamed 31: SW22#2.1; also elsewhere on the board
unnamed 33: L1#2.1 (DOUT), L2#2.3 (DIN); also elsewhere on the board
unnamed 34: L2#2.1 (DOUT), L3#2.3 (DIN); also elsewhere on the board
unnamed 35: L3#2.1 (DOUT), L4#2.3 (DIN); also elsewhere on the board
RST: SW24#2.1; also elsewhere on the board
VCC: L1#2.4 (VDD), L2#2.4 (VDD), L3#2.4 (VDD), L4#2.4 (VDD); also elsewhere on the board

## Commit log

2026-04-23 change case design and add bridge for backplate
    [pisicBackplate.dxf, pisicBackplateBridgeL.stl, pisicBackplateBridgeR.stl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]
2026-04-27 add case 3mf variants
    [pisic.3dm, pisicWireless.3mf]
2026-04-28 tweaked pcb for some space
    [pisic-B_Cu.gbr, pisic-B_Mask.gbr, pisic-B_Paste.gbr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]
2026-04-28 edited ground pour design
    [pisic-B_Cu.gbr, pisic-B_Mask.gbr, pisic-B_Paste.gbr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]
2026-04-28 enhance case: enforced fragile corner screws. also edited plates
    [pisic.3dm, pisicCaseWiredBridgedL.stl, pisicCaseWiredBridgedR.stl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]
2026-04-29 add image of finished pcb for buildguide
